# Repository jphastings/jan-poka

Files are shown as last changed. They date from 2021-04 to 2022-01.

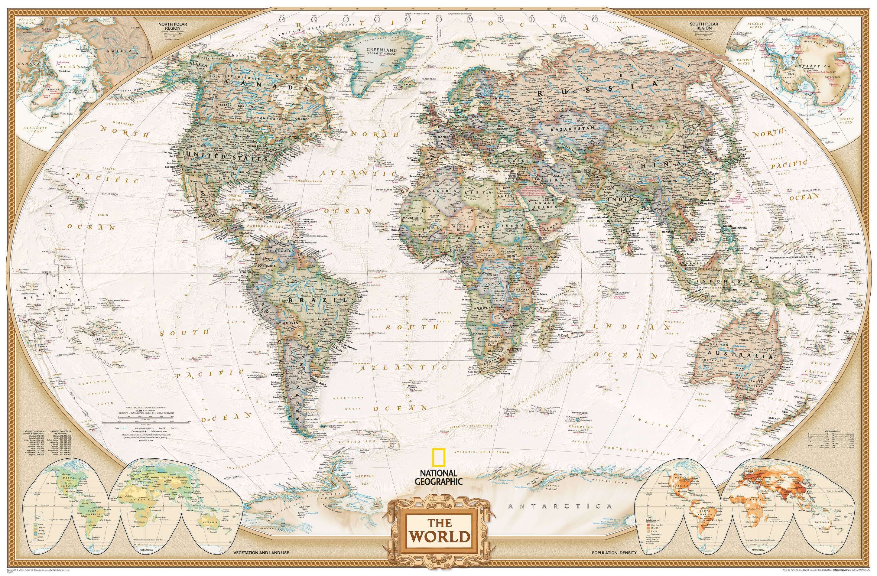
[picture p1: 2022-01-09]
docs/maps/national-geographic-world-executive-map_ng01096.jpg

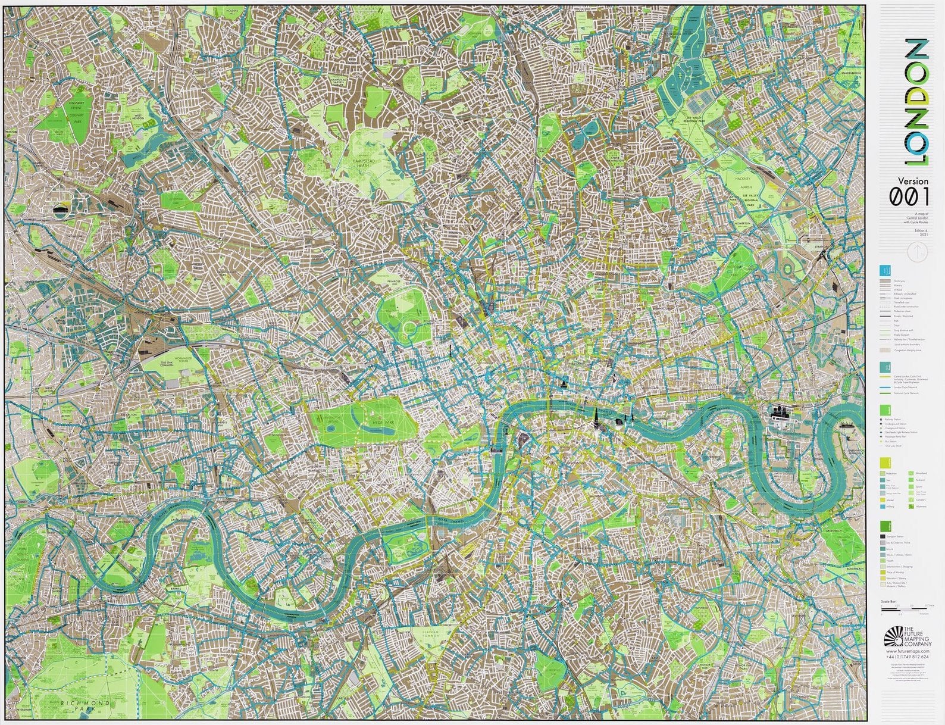
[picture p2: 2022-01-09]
docs/maps/future_maps-london-v001.jpg

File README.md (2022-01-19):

# Jan Poka

A device for bringing your distant friends a little nearer.

## Set up

Use docker to run anywhere:

```bash
docker run --env-file .env --network host ghcr.io/jphastings/jan-poka:latest
```

NB. You must run attached to the host network, as this service uses Bonjour service discovery, so needs to know its network-visible IP address.

(Assuming that you have appropriate environment variables in a file called `.env`)

## Options

While executing:

| $ENV_VAR | Functionality |
|---|---|
| $JP_HOMELATITUDE | The latitude of where the device is. |
| $JP_HOMELONGITUDE | The longitude of where the device is. |
| $JP_HOMEALTITUDE | The altitude of where the device is. |
| $JP_MQTTPORT | The port to run the MQTT broker on. |
| $JP_USEAUDIO | Allows audio playing — used by text-to-speech. (Requires [libasound2-dev](https://packages.debian.org/sid/libasound2-dev) on Linux) |

While building:

| build tag | Functionality |
|---|---|
| libnova | Allows celestial body location (Requires [libnova](http://libnova.sourceforge.net/)) |

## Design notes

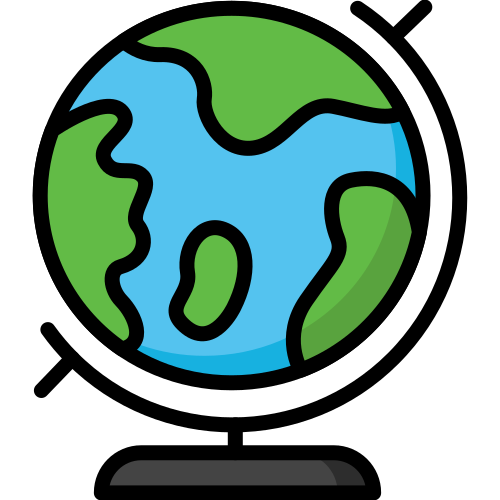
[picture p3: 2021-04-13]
docs/globe.png

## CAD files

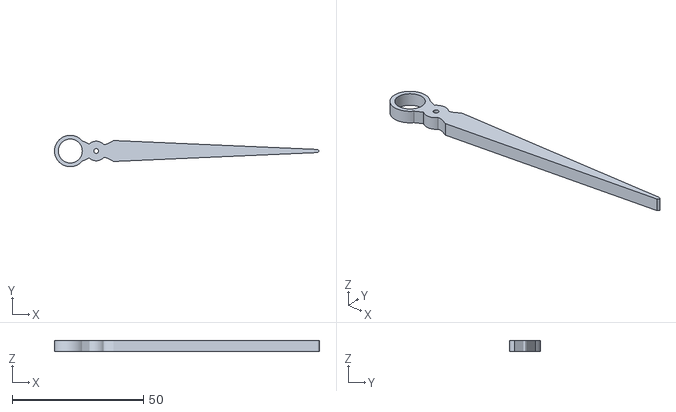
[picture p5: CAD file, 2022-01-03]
hardware/clock/3dmodel/minute-hand.stl
100.9 x 12.0 x 4.00

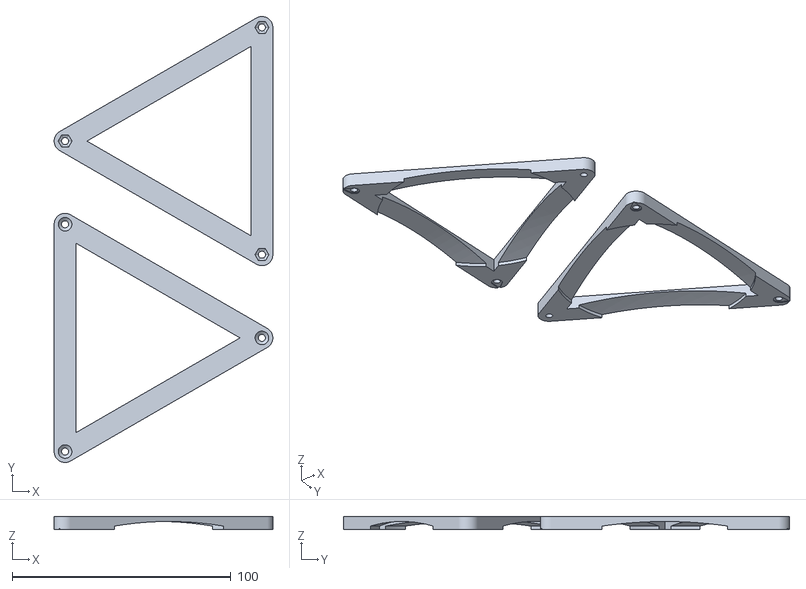
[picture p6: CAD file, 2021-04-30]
hardware/mapper/3dmodel/lens-holder.stl
100.0 x 203.9 x 6.00

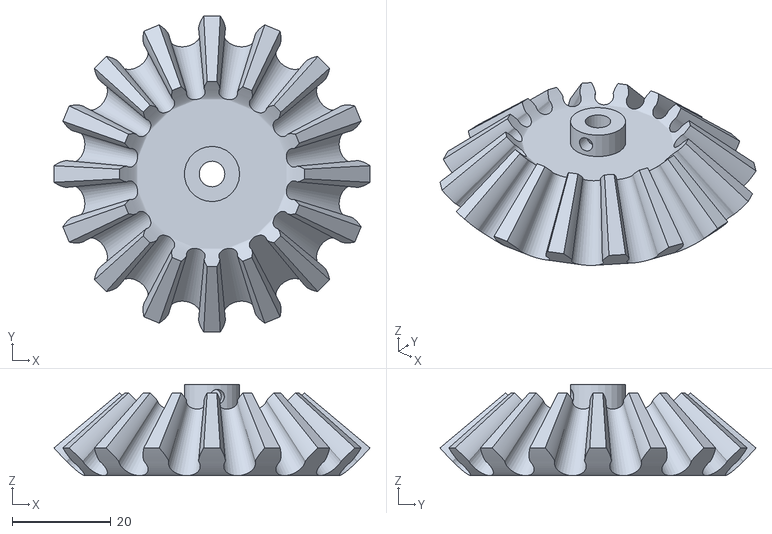
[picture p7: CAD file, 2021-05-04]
hardware/pointer/3dmodel/vertical_driving_gear.stl
64.1 x 64.1 x 18.5

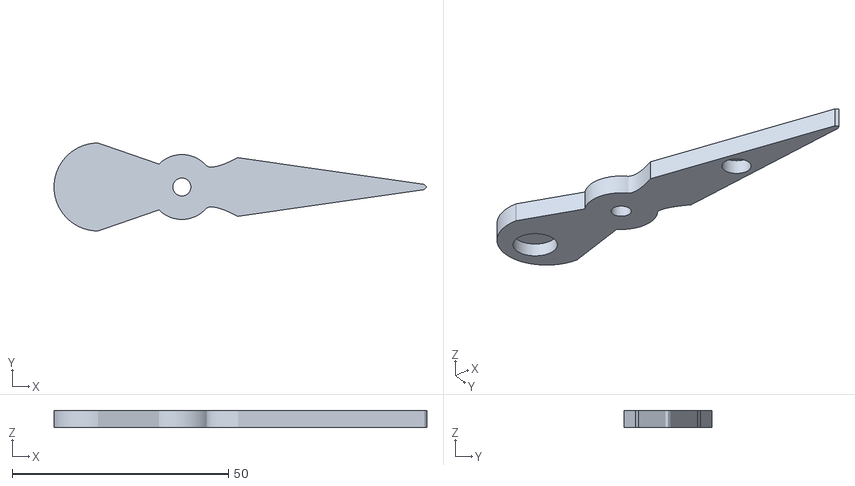
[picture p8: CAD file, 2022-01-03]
hardware/clock/3dmodel/hour-hand.stl
86.2 x 20.3 x 4.00

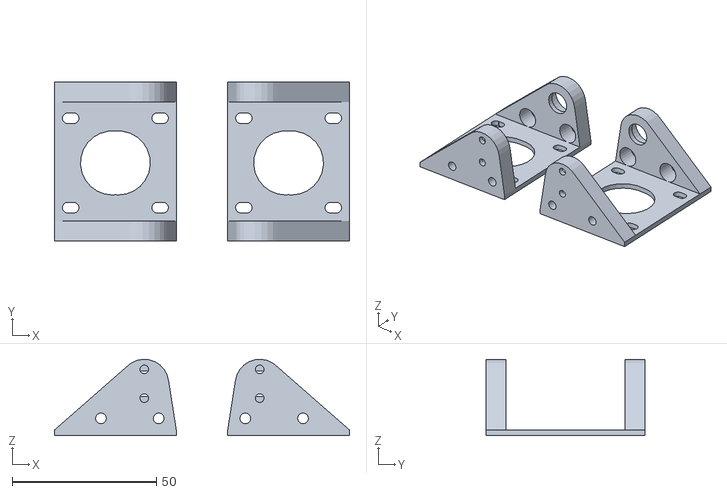
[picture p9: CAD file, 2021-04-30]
hardware/mapper/3dmodel/motor-brackets.stl
102.2 x 55.2 x 26.5

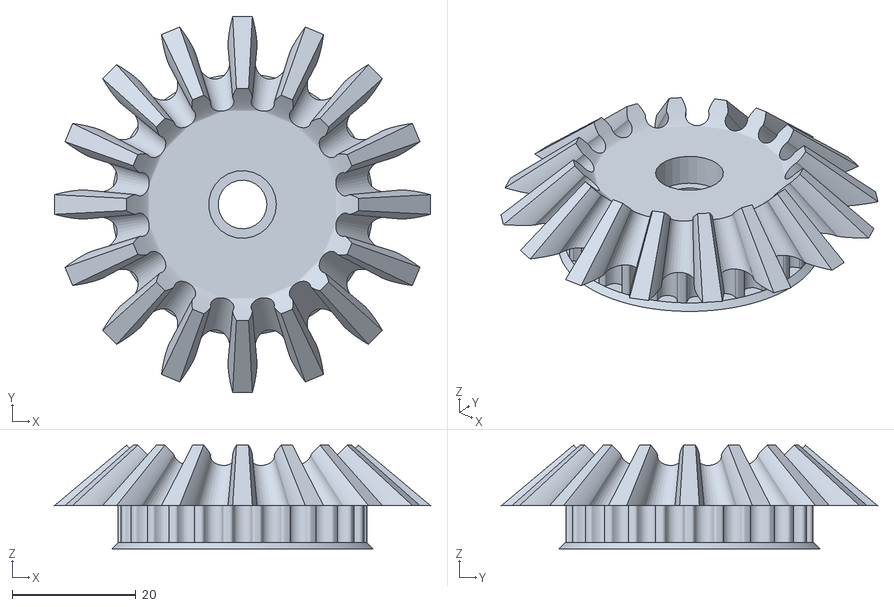
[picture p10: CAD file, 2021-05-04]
hardware/pointer/3dmodel/horizontal_gear.stl
60.8 x 60.8 x 16.8

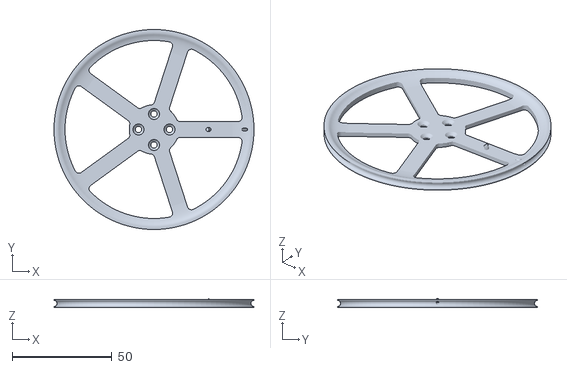
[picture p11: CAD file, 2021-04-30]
hardware/mapper/3dmodel/wheel.stl
100.0 x 100.0 x 4.47

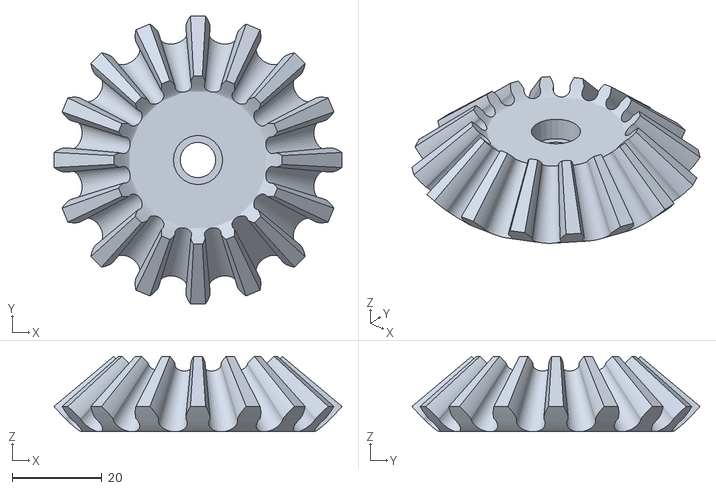
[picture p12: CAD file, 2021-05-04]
hardware/pointer/3dmodel/vertical_guiding_gear.stl
64.1 x 64.1 x 16.8

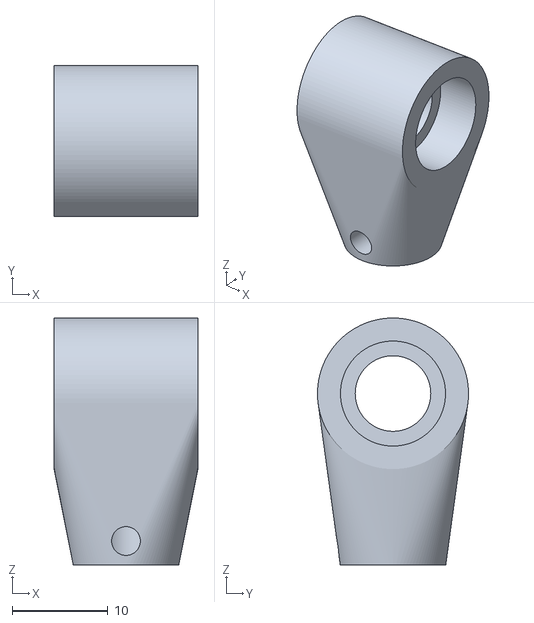
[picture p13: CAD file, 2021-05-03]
hardware/pointer/3dmodel/joint.stl
15.0 x 15.8 x 25.8

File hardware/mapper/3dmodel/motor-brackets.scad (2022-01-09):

use <../../../ext/openscad/hardware/rods.scad>;
use <../../../ext/openscad/hardware/screws.scad>;
use <../../../ext/openscad/MCAD/motors.scad>;
use <../../../ext/openscad/MCAD/stepper.scad>;

$fn=25;

module worm_wall_mount(tolerance = 0.1) {
  wall_thickness = 2;
  nema_17_thickness = 42.20;
  nema_backstep = 18;
  stepper_gap = 4;
  axel_offset = 10;

  bearing_height = 5;
  bearing_od = 13;
  bearing_housing_od = bearing_od+2*wall_thickness;
  bracket_thickness = bearing_height + wall_thickness;

  difference() {
    translate([axel_offset - nema_17_thickness/2, nema_backstep - wall_thickness, 0])
      cube([nema_17_thickness, wall_thickness, nema_17_thickness + 3*wall_thickness]);

    translate([axel_offset, nema_backstep, nema_17_thickness/2 + wall_thickness + stepper_gap])
      rotate([90, 90, 0])
      linear_extrude(wall_thickness)
      stepper_motor_mount(17, 2, true, tolerance);
  }


  translate([0, 0, wall_thickness]) {
    %bearing(4, bearing_od+2*tolerance, bearing_height+tolerance);
    %rod(4, 70);
  }
  translate([0, 0, nema_17_thickness + 4*wall_thickness])
    %bearing(4, bearing_od+2*tolerance, bearing_height+tolerance);

  module bracket() {
    difference() {
      hull() {
        cylinder(bracket_thickness, d=bearing_od+2*wall_thickness);
        translate([axel_offset - nema_17_thickness/2, nema_backstep - wall_thickness, 0])
          cube([nema_17_thickness, wall_thickness, bracket_thickness]);
      }

      translate([0, 0, wall_thickness])
        cylinder(bearing_height+tolerance, d=bearing_od+2*tolerance);
    }
  }

  difference() {
    bracket();
    translate([-5, 12, 0])
      countersunk_wallmount(3.5, bracket_thickness, tolerance = tolerance);
    translate([15, 12, 0])
      countersunk_wallmount(3.5, bracket_thickness, tolerance = tolerance);
    translate([0, 5, 0])
      cylinder(wall_thickness+tolerance, d=3);
    translate([0, -5, 0])
      cylinder(wall_thickness+tolerance, d=3);
  }


  difference() {
    translate([0, 0, nema_17_thickness + 3*wall_thickness])
      bracket();

    rod(9, 70);
    translate([-5, 12, nema_17_thickness + 2*wall_thickness])
      cylinder(bracket_thickness+2*wall_thickness, d=8);
    translate([15, 12, nema_17_thickness + 2*wall_thickness])
      cylinder(bracket_thickness+2*wall_thickness, d=8);
  }
}

translate([20, 0, 0])
  rotate([-90, 0, 0])
  worm_wall_mount();

translate([-20, 0, 0])
  rotate([-90, 0, 0])
  mirror([1, 0, 0]) worm_wall_mount();

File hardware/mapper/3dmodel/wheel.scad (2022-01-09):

include <../../../ext/openscad/hardware/bezier.scad>

RAD = 180 / PI;

flange_diameter = 22;
flange_holes = 4;
flange_holes_diameter = 15.5;
flange_hole_diameter = 3.1;
flange_countersink_diameter = 5.5;
flange_countersink_angle = 90;
flange_countersink_h = flange_countersink_diameter / (2 * tan(flange_countersink_angle/2));

cutaway_count = 5;
diameter = 100;
outer_thickness = 8;
rim = 0.5;
inner_thickness = 2;
hole_space = 4;
anchor_d = 2;

assert(anchor_d <= 2*hole_space, "The anchor is too wide to fit on the spokes");

spindle_diameter = (outer_thickness - rim * 2);
end = (diameter - outer_thickness)/2;

thread_diameter = 1.5;


module profile() {
    
    difference() {
        union() {
            translate([end, 0]) square([outer_thickness / 2, outer_thickness/2]);
            square([end, inner_thickness]);
            curve_width = diameter/2 - flange_diameter;
            curve(
                [flange_diameter, inner_thickness],
                [flange_diameter + 0.8 * curve_width, inner_thickness/2],
                [flange_diameter + 0.8 * curve_width, (outer_thickness + inner_thickness)*3/4],
                [diameter/2, outer_thickness]
            );
        }
       
        translate([diameter / 2, outer_thickness / 2]) circle(d = spindle_diameter);
    }
    
    
}


module hole(angle) {
    corner_r = 2;

    txc_y = (corner_r+hole_space);
    txc_x = txc_y * ( 1 / sin(angle) + 1/tan(angle));
    txc_r = sqrt(txc_x*txc_x + txc_y * txc_y);
    
    near = flange_diameter/2 + hole_space - txc_r;
    far = end - hole_space - txc_r;
    half = (near + far) / 2;
    
    assert(near * sin(angle) > 0, "Too many cutaways to fit :(");
    
    union() {
        translate([txc_x, txc_y, 0])
        hull() {
            translate([near * cos(0), near * sin(0), 0]) cylinder(outer_thickness, r = corner_r);
            translate([far * cos(0), far * sin(0), 0]) cylinder(outer_thickness, r = corner_r);
            translate([half * cos(angle/2), half * sin(angle/2), 0]) cylinder(outer_thickness, r = 1);
        }
        
        translate([txc_x, txc_y, 0])
        hull() {
            translate([near * cos(angle), near * sin(angle), 0]) cylinder(outer_thickness, r = corner_r);
            translate([far * cos(angle), far * sin(angle), 0]) cylinder(outer_thickness, r = corner_r);
            translate([half * cos(angle/2), half * sin(angle/2), 0]) cylinder(outer_thickness, r = 1);
        }
        
        
        arc_far_r = sqrt(txc_y^2 + (txc_x+far)^2);
        arc_near_r = sqrt(txc_y^2 + (txc_x+near)^2);
        arc_angle = 1.2; // TODO: Figure this through trig, instead of guessing
        difference() {
            intersection() {
                translate([txc_x, txc_y, 0])
                    linear_extrude(outer_thickness) polygon([
                        [-corner_r/2, -corner_r/2],
                        [(diameter-corner_r/2) * cos(arc_angle), (diameter-corner_r/2) * sin(arc_angle)],
                        [(diameter-corner_r/2) * cos(angle - arc_angle), (diameter-corner_r/2) * sin(angle - arc_angle)]
                    ]);
                cylinder(outer_thickness, r=arc_far_r+corner_r);
            }

            cylinder(outer_thickness, r=arc_near_r - corner_r);
        }
    }
}

module holes(count) {
    angle = 360 / count;
    for(i = [0:count -1]) {
        rotate([0, 0, i * angle])
        hole(angle);
    }
}
    

module curve(start, cp1, cp2, end, steps = $fn) {
    for(step = [steps:1]) {
        polygon(
            points=[
                [end[0], start[1]],
                PointOnBezCubic2D(start, cp1, cp2, end, step/steps),
                PointOnBezCubic2D(start, cp1, cp2, end, (step-1)/steps)],
            paths=[[0,1,2,0]]
        );
    }
}

$fn=100;

if ($preview) { %holes(cutaway_count); } // without difference for preview

difference() {
    rotate_extrude()
        profile();
    if (!$preview) { holes(cutaway_count); }; // this eats CPU, so only on full render

    translate([diameter/2, 0, outer_thickness/2]) rotate([0, -80, 0]) cylinder(spindle_diameter*2, d = thread_diameter);

    for (i = [0:flange_holes - 1]) {
        rotate(360*i/flange_holes) translate([flange_holes_diameter/2, 0, 0]) { cylinder(outer_thickness, d = flange_hole_diameter);
            translate([0, 0, inner_thickness - flange_countersink_h]) cylinder(flange_countersink_h, d1 = 0, d2 = flange_countersink_diameter);
        }
    }
}

//profile();

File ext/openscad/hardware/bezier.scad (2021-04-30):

//=====================================
// This is public Domain Code
// Contributed by: William A Adams
// 11 May 2011
//=====================================
joinfactor = 0.125;

gSteps = 4;
gHeight = 4;


//=======================================
// Functions
// These are the 4 blending functions for a cubic bezier curve
//=======================================

/*
	Bernstein Basis Functions

	For Bezier curves, these functions give the weights per control point.
*/
function BEZ03(u) = pow((1-u), 3);
function BEZ13(u) = 3*u*(pow((1-u),2));
function BEZ23(u) = 3*(pow(u,2))*(1-u);
function BEZ33(u) = pow(u,3);

// Calculate a singe point along a cubic bezier curve
// Given a set of 4 control points, and a parameter 0 <= 'u' <= 1
// These functions will return the exact point on the curve
function PointOnBezCubic2D(p0, p1, p2, p3, u) = [
	BEZ03(u)*p0[0]+BEZ13(u)*p1[0]+BEZ23(u)*p2[0]+BEZ33(u)*p3[0],
	BEZ03(u)*p0[1]+BEZ13(u)*p1[1]+BEZ23(u)*p2[1]+BEZ33(u)*p3[1]];

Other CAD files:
ext/openscad/hardware/rods.scad
ext/openscad/hardware/screws.scad
hardware/clock/3dmodel/hands.scad
hardware/mapper/3dmodel/lens-holder.scad
hardware/pointer/3dmodel/pointer.scad

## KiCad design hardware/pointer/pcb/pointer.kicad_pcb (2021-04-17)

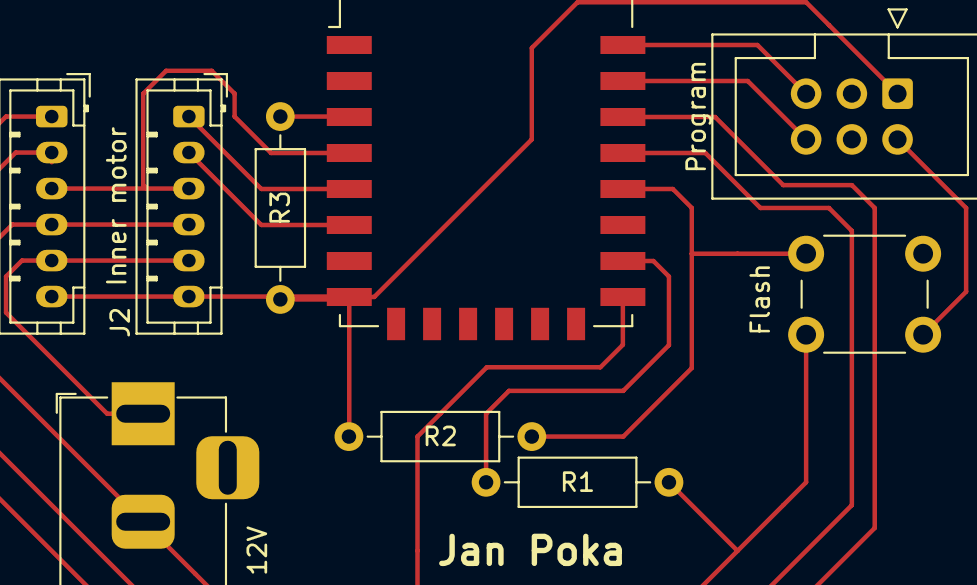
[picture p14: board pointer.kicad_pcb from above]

Board: 2 copper layers, 9 parts (0 on the bottom side), 13 nets.

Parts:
DC: 12V; BarrelJack_Horizontal
J1: Outer Motor; JST_PH_B6B-PH-K_1x06_P2.00mm_Vertical
J2: Inner motor; JST_PH_B6B-PH-K_1x06_P2.00mm_Vertical
J3: Program; IDC-Header_2x03_P2.54mm_Vertical
R1, R2, R3: 10k; R_Axial_DIN0207_L6.3mm_D2.5mm_P10.16mm_Horizontal
SW: Flash; SW_PUSH_6mm_H4.3mm
U1: ESP-12E

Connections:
+3V3: J1.6, J2.6, J3.1, R2.2, R3.2, U1.8
GND: DC.2, J1.4, J2.4, J3.2, R1.1, SW.2, U1.15
unnamed: DC.1, J1.5, J2.5
unnamed: J1.1, U1.20
unnamed: J1.2, U1.19
unnamed: J1.3, J2.3, U1.4
unnamed: J2.1, U1.5
unnamed: J2.2, U1.6
unnamed: J3.5, U1.22
unnamed: J3.6, U1.21
unnamed: R1.2, U1.16
unnamed: R2.1, SW.1, U1.18
unnamed: R3.1, U1.3

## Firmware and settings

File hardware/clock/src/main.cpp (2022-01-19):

#define ARDUINOJSON_USE_DOUBLE 1

#include <Arduino.h>
#include <AccelStepper.h>
#include <NeoPixelBus.h>
#include <PubSubClient.h>
#include <ArduinoJson.h>
#include <HTTPClient.h>
#include <ESPmDNS.h>
#include <WiFi.h>
#include <WiFiManager.h>
#include <time.h>
#include <sys/time.h>
#include <esp_sntp.h>
#include <sunset.h>

#define MQTT_TOPIC "home/geo/target"
#define MDNS_TARGET "Jan Poka"

#define APP_NAME "jan-poka:clock"
#define NTP_SERVER "time.google.com"
#define MOTOR_STEPS 720
#define MINS_STEPS MOTOR_STEPS / 60.0
#define HOURS_STEPS MOTOR_STEPS / 12.0
#define LED_COUNT 96
#define LED_FADE_AT LED_COUNT/3
#define LED_OFF_AT LED_COUNT*2/3
#define LED_MINS 12 * 60 / (float) LED_COUNT
#define UPDATE_FREQ_S 15

// Pins
#define LED_DATA_PIN 27
#define HALL_QANTIZATION 64

#define HOURS_STEPPER_A1 16
#define HOURS_STEPPER_A2 17
#define HOURS_STEPPER_B1 18
#define HOURS_STEPPER_B2 15
#define HOURS_HALL_SENSOR_PIN 34
#define HOURS_HALL_SENSOR_POS 360
#define HOURS_STEP_SPEED 200
#define HOURS_CALIB_STEP_SPEED 85

#define MINS_STEPPER_A1 19
#define MINS_STEPPER_A2 21
#define MINS_STEPPER_B1 23
#define MINS_STEPPER_B2 22
#define MINS_HALL_SENSOR_PIN 35
#define MINS_HALL_SENSOR_POS 356
#define MINS_STEP_SPEED 200
#define MINS_CALIB_STEP_SPEED 110

AccelStepper stepHour(AccelStepper::FULL4WIRE, HOURS_STEPPER_A1, HOURS_STEPPER_A2, HOURS_STEPPER_B1, HOURS_STEPPER_B2);
AccelStepper stepMin(AccelStepper::FULL4WIRE, MINS_STEPPER_A1, MINS_STEPPER_A2, MINS_STEPPER_B1, MINS_STEPPER_B2);

NeoPixelBus<NeoGrbwFeature, NeoSk6812Method> leds(LED_COUNT, LED_DATA_PIN);

WiFiClient wifiClient;
PubSubClient mqttClient(wifiClient);
time_t epoch;
struct tm *now;
int lastUpdated = -1;

SunSet sun;
RgbwColor dayCol(128, 64, 0, 128);
RgbwColor civilCol(128, 0, 64, 64);
RgbwColor astroCol(0, 0, 192, 16);
RgbwColor nightCol(0, 0, 255, 0);
RgbwColor offCol(0,0,0,0);

typedef struct {
  int minutesAfterMidnight;
  RgbwColor col;
} SkyChange;

#define SKY_CHANGE_COUNT 10
typedef struct {
  SkyChange changes[SKY_CHANGE_COUNT];
} SkyChanges;

struct StepperCalibration {
  long cumulativeReadings[MOTOR_STEPS];
  int countReadings[MOTOR_STEPS];
  bool calibrated;
  bool isMins;
};
struct StepperCalibration minsCalibrate;
struct StepperCalibration hoursCalibrate;
bool motorsCalibrating;

void setupWifi(bool);
void setupMQTT();
void setupTime();
void setupMotors();
void setupLEDs();

void updateTime();
void updateClock();
void updateMotors();
void updateLEDs();
void loopMQTT();
void loopClock();

void handleGeoTarget(char*, byte*, unsigned int);
bool steppersMoving();
void calibrateMotors();
int timeToDayMins(int, int);
void startMotorCalibration();

int updatedInt();
void setTimezone(double, double, int, int);
void normalizeStepper(AccelStepper*);
void moveCircular(AccelStepper*, long);

int normalizeStepCount(int pos) {
  if (pos < 0) {
      pos += -(pos/MOTOR_STEPS)*MOTOR_STEPS + MOTOR_STEPS;
  }
  return pos % MOTOR_STEPS;
}

void setupWifi(bool setLeds) {
  // Show LEDs; it shows WHIte at FIve, geddit?
  if (setLeds) {
    int wiFiveOclock = 11*LED_COUNT/12 - 2;
    leds.SetPixelColor(wiFiveOclock, RgbwColor(128,128,128,128));
    leds.Show();
  }

  // Connect to WiFi
  WiFi.mode(WIFI_STA);
  WiFiManager wifiManager;
  bool success = wifiManager.autoConnect(APP_NAME);
  if(!success) {
      Serial.println("Failed to connect using WiFi manager");
  } else {
      Serial.println("Connected using WiFi manager");
  }

  // Start mDNS
  if(mdns_init() != ESP_OK) {
    Serial.println("mDNS failed to start");
    return;
  }

  // Stop showing LEDs
  if (setLeds) {
    leds.ClearTo(offCol);
    leds.Show();
  }
}

void loopMQTT() {
  if (!mqttClient.connected()) {
    // TODO: Pick random name for username
    if (!mqttClient.connect(APP_NAME, "clock", "")) {
      Serial.println("Failed to connect to MQTT broker");
      return;
    }
    mqttClient.setCallback(handleGeoTarget);
    if (!mqttClient.subscribe(MQTT_TOPIC, 0)) {
      Serial.println("Failed to subscribe to the geo target topic");
      return;
    }
  }
  mqttClient.loop();
}

void setupMQTT() {
  mqttClient.setBufferSize(1024);

  IPAddress ip;
  uint16_t port = 0;

  while (true) {
    int countServices = MDNS.queryService("_jan_poka_mqtt", "_tcp");
    if (countServices == 0) {
      Serial.println("No Jan Poka MQTT services visible over mDNS. Please turn on Jan Poka controller.");
      delay(500);
      continue;
    }
    
    if (countServices > 1) {
      Serial.println("More than one Jan Poka controller was found, using the first.");
    }
    
    ip = MDNS.IP(0);
    port = MDNS.port(0);

    if (port != 0) {
      break;
    }

    Serial.println("mDNS returned a service with invalid port, trying again");
    delay(500);
  }

  Serial.print("Connected to MQTT: ");
  Serial.print(ip); Serial.print(":"); Serial.println(port);

  mqttClient.setServer(ip, port);
  loopMQTT();
}


void setupTime() {
  sntp_setoperatingmode(SNTP_OPMODE_POLL);
  sntp_setservername(0, NTP_SERVER);
  sntp_init();
}

void setupMotors() {
  stepMin.setMaxSpeed(MINS_CALIB_STEP_SPEED);
  stepMin.setAcceleration(200.0);
  stepMin.setCurrentPosition(0);

  stepHour.setMaxSpeed(HOURS_CALIB_STEP_SPEED);
  stepHour.setAcceleration(200.0);
  stepHour.setCurrentPosition(0);

  startMotorCalibration();
}

void setupLEDs() {
  leds.Begin();
  leds.ClearTo(offCol);
  leds.Show();
}

void handleGeoTarget(char* topic, byte* payload, unsigned int length) {
  Serial.println("MQTT message received");
  /* Copied from EspMQTTClient: https://github.com/plapointe6/EspMQTTClient/blob/master/src/EspMQTTClient.cpp#L649 */
  // Convert the payload into a String
  // First, We ensure that we dont bypass the maximum size of the PubSubClient library buffer that originated the payload
  // This buffer has a maximum length of _mqttClient.getBufferSize() and the payload begin at "headerSize + topicLength + 1"
  unsigned int strTerminationPos;
  if (strlen(topic) + length + 9 >= mqttClient.getBufferSize()) {
    strTerminationPos = length - 1;
  } else {
    strTerminationPos = length;
  }
  
  // Second, we add the string termination code at the end of the payload
  payload[strTerminationPos] = '\0';
  /* end */

  StaticJsonDocument<1024> doc;
  DeserializationError err = deserializeJson(doc, payload, strTerminationPos + 1);
  if (err != DeserializationError::Ok) {
    Serial.print("Unsuccessful at parsing MQTT JSON: ");
    Serial.println(err.c_str());
    return;
  }
  setTimezone(doc["lat"], doc["lng"], doc["tutc"], doc["tdst"]);
}

bool steppersMoving() {
  return stepMin.distanceToGo() != 0 || stepHour.distanceToGo() != 0;
}

int timeToDayMins(int hours, int mins) {
  return (hours * 60 + mins);
}

void updateClock() {
  if (now == 0 || steppersMoving() || motorsCalibrating)
    return;

  Serial.print("Setting time to: "); Serial.print(now->tm_hour); Serial.print(":"); Serial.print(now->tm_min); Serial.print(":"); Serial.println(now->tm_sec);

  updateMotors();
  updateLEDs();
    
  lastUpdated = updatedInt();
}

void loopClock() {
  if (lastUpdated == updatedInt())
    return;
  updateClock();
}

int updatedInt() {
  return (now->tm_min * 60 + now->tm_sec) / UPDATE_FREQ_S;
}

void updateMotors() {
  moveCircular(&stepMin, (now->tm_min + now->tm_sec/60.0) * MINS_STEPS);
  moveCircular(&stepHour, (now->tm_hour + now->tm_min/60.0) * HOURS_STEPS);
}


SkyChanges calculateSkyChanges() {
  SkyChanges s;

  // Set the sky type for midnight; will be dark unless there was no sunset yesterday
  now->tm_mday--;
  sun.setCurrentDate(now->tm_year, now->tm_mon, now->tm_mday);
  now->tm_mday++;
  s.changes[0].minutesAfterMidnight = 0;
  s.changes[0].col = (sun.calcSunset() == 0) ? dayCol : nightCol;

  sun.setCurrentDate(now->tm_year, now->tm_mon, now->tm_mday);
  s.changes[1].minutesAfterMidnight = sun.calcAstronomicalSunrise();
  s.changes[1].col = astroCol;
  s.changes[2].minutesAfterMidnight = sun.calcCivilSunrise();
  s.changes[2].col = civilCol;
  s.changes[3].minutesAfterMidnight = sun.calcSunrise();
  s.changes[3].col = dayCol;
  s.changes[4].minutesAfterMidnight = sun.calcSunset();
  s.changes[4].col = civilCol;
  s.changes[5].minutesAfterMidnight = sun.calcCivilSunset();
  s.changes[5].col = astroCol;
  s.changes[6].minutesAfterMidnight = sun.calcAstronomicalSunset();
  s.changes[6].col = nightCol;

  now->tm_mday++;
  sun.setCurrentDate(now->tm_year, now->tm_mon, now->tm_mday);
  now->tm_mday--;
  s.changes[7].minutesAfterMidnight = 24 * 60 + sun.calcAstronomicalSunrise();
  s.changes[7].col = astroCol;
  s.changes[8].minutesAfterMidnight = 24 * 60 + sun.calcCivilSunrise();
  s.changes[8].col = civilCol;
  s.changes[9].minutesAfterMidnight = 24 * 60 + sun.calcSunrise();
  s.changes[9].col = dayCol;

  return s;
}

RgbwColor colAtMins(SkyChanges s, int minsAfterMidnight) {
  RgbwColor col = s.changes[0].col;

  for (int i = 1; i < SKY_CHANGE_COUNT; i++) {
    if (minsAfterMidnight < s.changes[i].minutesAfterMidnight) {
      return col;
    }
    col = s.changes[i].col;
  }

  return col;
}

void updateLEDs() {
  int nowMins = timeToDayMins(now->tm_hour, now->tm_min);
  // The time in minutes now, scaled to fit into the number of LEDs, offset by half as 0th pixel is at 6 o'clock
  int nowPos = (nowMins * LED_COUNT / (12 * 60) + (LED_COUNT / 2)) % LED_COUNT;

  SkyChanges skyChanges = calculateSkyChanges();

  leds.ClearTo(offCol);
  for (int i = 0; i < LED_OFF_AT; i++) {
    int iMins = (int)(i*LED_MINS + nowMins) % (24 * 60);
    RgbwColor col = colAtMins(skyChanges, iMins);

    float fadeAmount = (i < LED_FADE_AT) ? 0 : ((i - LED_FADE_AT) / (float)(LED_OFF_AT - LED_FADE_AT));
    col = RgbwColor::LinearBlend(col, offCol, fadeAmount);
    
    int pos = (i + nowPos) % LED_COUNT;
    leds.SetPixelColor(pos, col);
  }
  leds.Show();
}

void moveCircular(AccelStepper* stepper, long steps) {
    // normalizeStepper(stepper);
    // Move Backwards if it's faster
    // long curPos = -stepper->currentPosition(); // -ve for clockwise correction
    // long newPos = steps % MOTOR_STEPS;
    // if (newPos - curPos > MOTOR_STEPS/2) {
    //   newPos = MOTOR_STEPS - newPos;
    // }
    // else if (newPos - curPos + MOTOR_STEPS < MOTOR_STEPS/2) {
    //   newPos += MOTOR_STEPS;
    // }
    
    stepper->moveTo(normalizeStepCount(-steps)); // -ve for clockwise correction
}

void setTimezone(double latitude, double longitude, int utcOffsetMins, int dstOffsetMins) {
  Serial.print("Setting timezone offsets. UTC: "); Serial.print(utcOffsetMins); Serial.print(", DST: "); Serial.println(dstOffsetMins);
  sun.setPosition(latitude, longitude, (utcOffsetMins + dstOffsetMins) / 60.0);
  configTime(utcOffsetMins * 60, dstOffsetMins * 60, NTP_SERVER);
  updateTime();
  updateClock();
}

void updateTime() {
  time(&epoch);
  now = localtime(&epoch);
}

int guessHomePosition(long cumulativeReadings[MOTOR_STEPS], int countReadings[MOTOR_STEPS]) {
  int bestGuessPosFirst = 0;
  int bestGuessPosLast = 0;
  int lowestReading = 10000;

  for (int pos = 0; pos < MOTOR_STEPS; pos++) {
    if (countReadings[pos] == 0)
      continue;

    int val = (cumulativeReadings[pos] / countReadings[pos]) / HALL_QANTIZATION;
    // Serial.print(calibration->isMins); Serial.print(","); Serial.print(pos); Serial.print(","); Serial.println(val);
    if (val < lowestReading) {
      lowestReading = val;
      bestGuessPosFirst = pos;
      bestGuessPosLast = pos;
    } else if (val == lowestReading) {
      bestGuessPosLast = pos;
    }
  }

  return (bestGuessPosFirst + bestGuessPosLast) / 2;
}

void startMotorCalibration() {
  minsCalibrate = {.cumulativeReadings = {}, .countReadings = {}, .calibrated = false, .isMins = true};
  hoursCalibrate = {.cumulativeReadings = {}, .countReadings = {}, .calibrated = false, .isMins = false};
  motorsCalibrating = true;

  stepMin.moveTo(-MOTOR_STEPS*2);
  stepHour.moveTo(MOTOR_STEPS*2);
}

bool calibrateMotorStep(AccelStepper* stepper, struct StepperCalibration* calibration, int pin, int sensorPos) {
  if (calibration->calibrated)
    return true;

  int pos = normalizeStepCount(stepper->currentPosition());
  int reading = analogRead(pin);
  calibration->cumulativeReadings[pos] += reading;
  calibration->countReadings[pos]++;

  if (stepper->isRunning())
    return false;

  int bestGuessPos = guessHomePosition(calibration->cumulativeReadings, calibration->countReadings);

  int actualPos = normalizeStepCount(pos - bestGuessPos + sensorPos);

  stepper->setCurrentPosition(actualPos);
  stepper->moveTo(0);
  calibration->calibrated = true;
  return true;
}

void calibrateMotors() {
  bool minsGood = calibrateMotorStep(&stepMin, &minsCalibrate, MINS_HALL_SENSOR_PIN, MINS_HALL_SENSOR_POS);
  bool hoursGood = calibrateMotorStep(&stepHour, &hoursCalibrate, HOURS_HALL_SENSOR_PIN, HOURS_HALL_SENSOR_POS);
  if (minsGood && hoursGood) {
    Serial.println("Finished calibrating motors.");
    stepMin.setMaxSpeed(MINS_STEP_SPEED);
    stepHour.setMaxSpeed(HOURS_STEP_SPEED);
    motorsCalibrating = false;
  }
};

void setup() {
  Serial.begin(115200);

  setupLEDs();
  setupWifi(true);
  setupMQTT();
  setupMotors();
  setupTime();
  Serial.println("Booted");
}

void loop() {
  updateTime();
  
  stepMin.run();
  stepHour.run();

  if (motorsCalibrating)
    calibrateMotors();
  
  loopClock();
  loopMQTT();
}

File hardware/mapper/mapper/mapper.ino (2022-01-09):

#include <WiFiManager.h>
#include <PubSubClient.h>
#include <AccelStepper.h>
#include <ArduinoJson.h>
#include <math.h>
#include "vars.h";

#define APP_NAME "jan-poka:mapper"
#define ONE_ROTATION_STEPS 8192
#define POWER_OFF_DELAY 2000
#define MAX_SPEED 65536
#define ACCELERATION 4096
#define MQTT_POSITION_TOPIC MQTT_TOPIC "/" APP_NAME

int INNER_DIR     = 14; // D5
int INNER_STP     = 13; // D7
int INNER_DISABLE = 12; // D6
int OUTER_DIR     = 4;  // D2
int OUTER_STP     = 5;  // D1
int OUTER_DISABLE = 16; // D0
int BOOTING       = 2;  // D4

WiFiClient wifiClient;
PubSubClient mqttClient(wifiClient);

AccelStepper leftWheel = AccelStepper(AccelStepper::DRIVER, INNER_STP, INNER_DIR);
AccelStepper rightWheel = AccelStepper(AccelStepper::DRIVER, OUTER_STP, OUTER_DIR);

void setup() {
  Serial.begin(115200);
  pinMode(BOOTING, OUTPUT);
  digitalWrite(BOOTING, HIGH);
  pinMode(INNER_DISABLE, OUTPUT);
  digitalWrite(INNER_DISABLE, LOW);
  pinMode(OUTER_DISABLE, OUTPUT);
  digitalWrite(OUTER_DISABLE, LOW);

  mqttClient.setServer(MQTT_HOST, MQTT_PORT);

  leftWheel.setMaxSpeed(MAX_SPEED);
  rightWheel.setMaxSpeed(MAX_SPEED);
  leftWheel.setAcceleration(ACCELERATION);
  rightWheel.setAcceleration(ACCELERATION);
  leftWheel.setPinsInverted(true, false, false);
  rightWheel.setPinsInverted(true, false, false);

  mqttConnectionLoop();
  Serial.println("\nBooted");
  digitalWrite(BOOTING, LOW);
}

void mqttConnectionLoop() {
  if (!mqttClient.connected()) {
    if (!mqttClient.connect(APP_NAME, MQTT_USER, MQTT_PASS)) {
      Serial.println("Failed to connect to MQTT broker");
      // TODO: Backoff
      delay(1000);
      return;
    }
    Serial.println("MQTT connected");
    mqttClient.setCallback(handleGeoTarget);
    mqttClient.subscribe(MQTT_TOPIC);
  }
  mqttClient.loop();
}

void handleGeoTarget(char* topic, byte* payload, unsigned int length) {
  /* Copied from EspMQTTClient: https://github.com/plapointe6/EspMQTTClient/blob/master/src/EspMQTTClient.cpp#L649 */
  // Convert the payload into a String
  // First, We ensure that we dont bypass the maximum size of the PubSubClient library buffer that originated the payload
  // This buffer has a maximum length of _mqttClient.getBufferSize() and the payload begin at "headerSize + topicLength + 1"
  unsigned int strTerminationPos;
  if (strlen(topic) + length + 9 >= mqttClient.getBufferSize()) {
    strTerminationPos = length - 1;
  } else {
    strTerminationPos = length;
  }

  // Second, we add the string termination code at the end of the payload and we convert it to a String object
  payload[strTerminationPos] = '\0';
  String payloadStr((char*)payload);
  /* end */

  StaticJsonDocument<512> jsonDoc;
  DeserializationError err = deserializeJson(jsonDoc, payload);
  if (err != DeserializationError::Ok) {
    Serial.print("Unsuccessful at parsing MQTT JSON: ");
    Serial.println(err.f_str());
    return;
  }

  if (jsonDoc["reset"]) {
    leftWheel.setCurrentPosition(0);
    rightWheel.setCurrentPosition(0);
    publishPosition();
  }
  goTo(jsonDoc["r1"], jsonDoc["r2"]);
}

void goTo(double r1, double r2) {
  Serial.print("Going to, r1=");
  Serial.print(r1);
  Serial.print(", r2=");
  Serial.println(r2);

  leftWheel.moveTo(r1 * ONE_ROTATION_STEPS);
  rightWheel.moveTo(r2 * ONE_ROTATION_STEPS);
}

void publishPosition() {
  double r1 = leftWheel.currentPosition() / (double) ONE_ROTATION_STEPS;
  double r2 = rightWheel.currentPosition() / (double) ONE_ROTATION_STEPS;

  char buffer[64];
  sprintf(buffer, "{\"r1\":%.3f,\"r2\":%.3f}", r1, r2);
  mqttClient.publish(MQTT_POSITION_TOPIC, buffer);
}

unsigned long powerOffAt = 0;
bool wasMoving = false;

void loop() {
  bool noMove = leftWheel.distanceToGo() == 0 && rightWheel.distanceToGo() == 0;
  if (noMove) {
    if (powerOffAt == 0 && wasMoving) {
      powerOffAt = millis() + POWER_OFF_DELAY;
      publishPosition();
    } else if (millis() >= powerOffAt && wasMoving) {
      digitalWrite(INNER_DISABLE, HIGH);
      digitalWrite(OUTER_DISABLE, HIGH);
      powerOffAt = 0;
      wasMoving = false;
    }
  } else {
    digitalWrite(INNER_DISABLE, LOW);
    digitalWrite(OUTER_DISABLE, LOW);
    wasMoving = true;
  }

  leftWheel.run();
  rightWheel.run();
  mqttConnectionLoop();
}

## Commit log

2018-12-30 Swap to lower case
2018-12-30 Try stepper
2018-12-30 Faster…
2018-12-30 Use the right pin number…
2018-12-30 Stepper method
2019-01-02 Sleep motor inbetween turns
2019-01-02 Switch to quarter stepping
2019-01-02 A little slower…
2019-01-03 Refactor for Balena
    Support for the RPi; refactor to allow different plugins, set up just the one motor for now.
2019-01-03 Support Motor Sleeping
    Automatically sleep the motors after movement is complete. Currently might cause trouble, as it's done with timing rather than actual promises.
    If the motor stepping takes longer than estimated then the non-promise system in place will have trouble and the motors will be powered down before the steps are complete.
2019-01-03 Debug logging
    Somethings up, the stepper is going _very_ slowly — let's see what's going on!
2019-01-03 Swap to a channel/promise type system
    Use channels as a way of scheduling the motor movements without innaccurate timing
2019-01-03 Swap to using names not greek letters
    Greek letters are cool and all, but no-one knows which one's which, and they raise warnings in the compiler 😅
2019-01-06 Build flags to help development
    Because I can use TTS only locally (currently) and the RPi Hardware calls only on the device, use the golang build systems to allow selective compilation.
2019-01-06 Fix typo
    Ensure we declare that we're powering _down_ the motors.
2019-11-21 Looks like it's working with steppers!
2019-12-25 Models! Directions!
    Should have fixed directions, also models included!
    [arrow.stl, base.stl, head.stl]
2021-04-11 Added celestial body tracker
    Uses libnova to track locations of the planets, the sun and the moon.
    `brew install libnova` should get you sorted!
2021-04-11 Add concentric gear pointer device
    Adds the Arduino code for Chris' concertic gear pointer device, written for esp8266
2021-04-17 Add KiCAD designs
    [pointer.kicad_pcb, pointer.sch]
2021-04-30 Start combining other repos
    - Contains all current 3d models
    - Contains initial (very incomplete) PCB designs
    - Contains vendored OpenSCAD repos, for the 3d models
    [arrow.stl, base.stl, head.stl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]
2021-04-30 Remove direct RPi tooling
    Jan Poka has become a server, with lower powered devices controlling the stepper motors (as they're more capable of controlling them smoothly, and without issues)
    I've removed the 'tower' information, but this commit remains if I ever wish to bring it back.
2021-05-03 First part of pointer model; joint
    [joint.stl, pointer.scad]
2021-05-04 First pass at working timing belt
    [horizontal_gear.stl, pointer.scad, vertical_driving_gear.stl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]
2021-05-08 Woking timing belt
    [pointer.scad]
2021-05-14 Improve pointer; arrow not right yet
    [bezier.scad, lens-holder.scad, pointer.scad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]
2021-09-01 Add Mapper maths & framework for web mapper.
2022-01-02 Not quite complete calibration
2022-01-02 Hunting a minimum progressively doesn't work
    [main.cpp]
2022-01-02 It works!
    Also added OpenSCAD files for clock hands.
    [2d_points.scad, hands.scad, hour-hand.stl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]
2022-01-03 Move 2dpoints to vendor folder
    [hands.scad]
2022-01-06 Fix MQTT message size overload for clock
    [main.cpp]
2022-01-09 Calculate sunrise/set on device
2022-01-09 Retain MQTT messages so restarting devices are accurate
2022-01-09 Move openscad to ext
    [hands.scad, motor-brackets.scad, pointer.scad]
2022-01-19 Fix build on push
    The `create` trigger runs on every ref that's created (irrespective of the `tags` filter below).
    Switch back to `push` while I debug why this isn't working.
